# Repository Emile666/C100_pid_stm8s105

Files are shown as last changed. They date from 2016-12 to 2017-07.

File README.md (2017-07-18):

# C100_PID_Upgrade
------------------

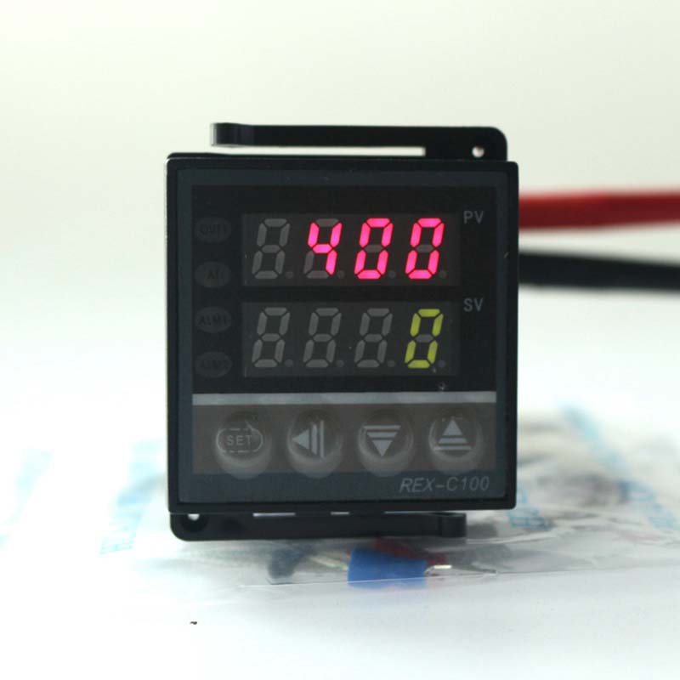
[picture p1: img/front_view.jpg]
C100_front_view
  
*Picture of the frontpanel of a C100 PID controller*

The C100 PID Controller is very easy to find on ebay. For only $10-$15 you can have a PID controller with SSR output. Most package-deals also include a Solid-State Relay (SSR) and a thermocouple (K-type) temperature sensor. Not a bad deal, but if you open the device and look at it from an electrical engineering perspective, things are starting to look a bit different. The main purpose of the upgrade given here is to change the default functionality into that found in the [STC1000p firmware](https://github.com/Emile666/stc1000_stm8/), with the 6 temperature profiles and up-to 9 temperature-time pairs per profile.

The main disadvantages of this controller are:
- K-type thermocouples are not really accurate (±2 °C is quite common)
- The thermocouple interface does not add much to this accuracy. Basically it is a opamp with a gain of 200. Very cheap indeed, no cold-junction compensation and not very accurate.
- Although the PCB has the option of interfacing with a RTD (PT100) sensor, it is not populated. A PT100 would be better suited for a -50 ... + 100 °C range that homebrewers typically use.
- No selectable temperature profiles like the STC1000p has.
- No alarm output relay populated
- Only one frontpanel LED mounted

Advantages are:
- Very nice small package
- Nice frontpanel PCB with 2 x 4-digit 7-segment displays
- Four buttons
- 110-240 V AC power-supply

Internal hardware consists of three Printed-Circuit Boards (PCB): the frontpanel PCB, the power-supply PCB and the main-PCB (as we will call them from now on). The power-supply PCB takes care of converting the AC wall-outlet voltage into a fixed 12 V and a 5 V DC voltage. It also contains the SSR output function.

The frontpanel PCB contains the 7-segment display (top and bottom row of 4-digits), four buttons and one output LED. It is connected to the main-PCB via a 14 pin soldered connection.

The main-PCB contains the microcontroller and the temperaturesensor interface electronics. The microcontroller itself is some crappy Chinese 8051 clone without decent manuals.

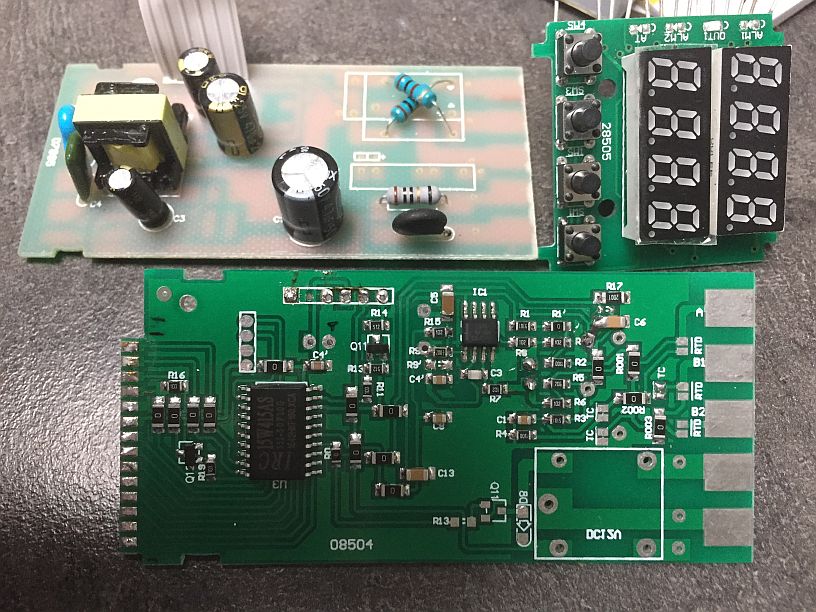
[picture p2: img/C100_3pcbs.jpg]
C100_3_pcbs
  
*Picture of the 3 PCBs taken apart*

# C100 Features after upgrade
---------------------------
- Menu functionality as found in the [STC1000p firmware](https://github.com/Emile666/stc1000_stm8/)
- Alarm relay output added
- Reliable and accurate temperature interface, both for a K-type thermocouple as well as for a PT100 element
- Wireless communication via a **nRF24L01+** device (not implemented yet)
- **I<sup>2</sup>C**-interface available for a DS3231 Real-Time Clock (RTC) interface, so you can have date and time in your C100 (not implemented yet)
- Both a K-type thermocouple and a PT100 are supported. Not at the same time, but if you replace a thermocouple for a PT100 sensor, this will work without further hardware modifications. Which sensor is connected, is detected automatically by the firmware.

Hardware Upgrade
------------------
The power-supply PCB and the frontpanel PCB are kept as they are. Only addition made to the frontpanel PCB is to add 3 more LEDs (ALM1, ALM2 and AT). These are 0805 SMD type LEDs: ALM1 and ALM2 LEDs are red, the AT LED is green.

The main-PCB is desoldered from the frontpanel PCB and thrown away. The interface electronics is horrible and the cheap Chinese microcontroller is of not much use: I don't know how to program it and there's no information how to do this. Instead, a new main-PCB with a decent microcontroller (**STM8S105C6T6**) is made. Schematics and PCB-layout of this new main-PCB is given below.

Software upgrade
-----------------
A port of the STC1000p firmware is made and made available in the src subdirectory (this is work-in-progress)

Schematics and PCB design
-------------------------

The frontpanel PCB is reverse-engineered and schematics are made. This is needed to understand how the frontpanel PCB operates.

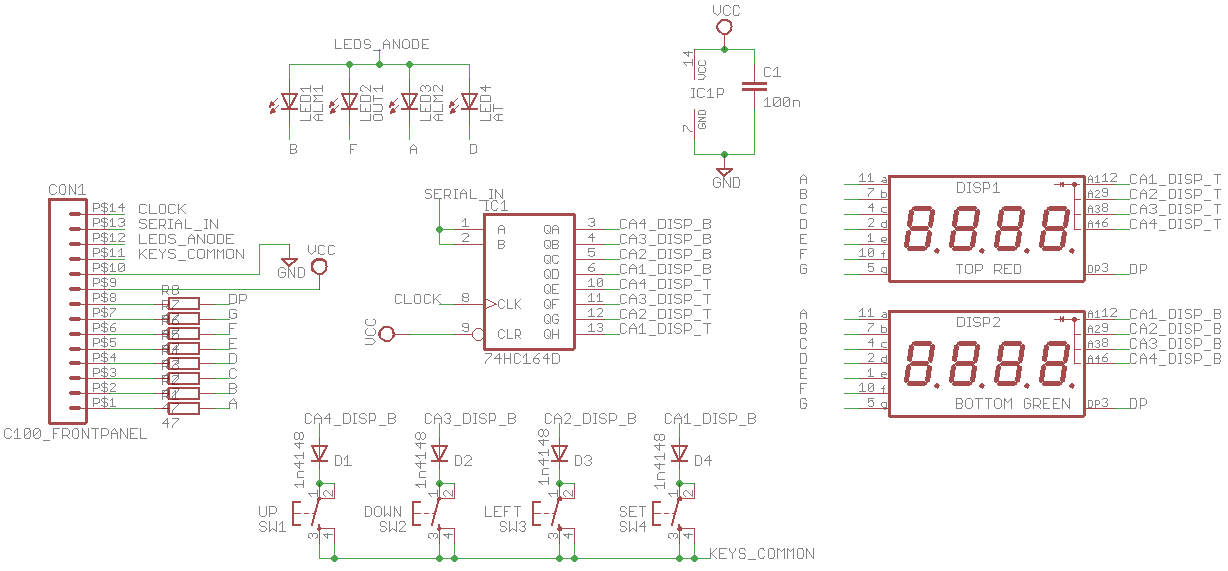
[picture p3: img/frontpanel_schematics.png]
C100 frontpanel
  
*Schematics of the frontpanel of the C100 PID controller*

Some interesting things can be seen from this:
- The Common-Anode lines (8 in total, one for every 7-segment display) are the outputs of a 74HC164 shift-register. The microcontroller controls this with the clock and serial_in lines.
- The keys are multiplexed with the Common-Anode lines from the 7-segment displays. When the displays are addressed, this line needs to be high. Reading the keys is done by enabling the CA lines one by one while checking if KEYS_COMMON line is high (key pressed) or low (not pressed). Furthermore, there's a pull-down resistor on these lines on the main-PCB.
- There's a separate LEDS_ANODE line for the four LEDs (of which only the OUT1 LED is populated). Set this low to disable the LEDs, high with the proper (B, F, A or D) line low enables the LED. A separate PNP transistor to drive this line is populated at the main-PCB.
- The 14 pin connector to the main-PCB is a soldered connection. Place the two PCBs against each other and solder every individual pin.
- The individual segments (a, b, c, d, e, f, g and dp) are connected via a 47R resistor directly to the main-PCB.

The main-PCB is created completely new:

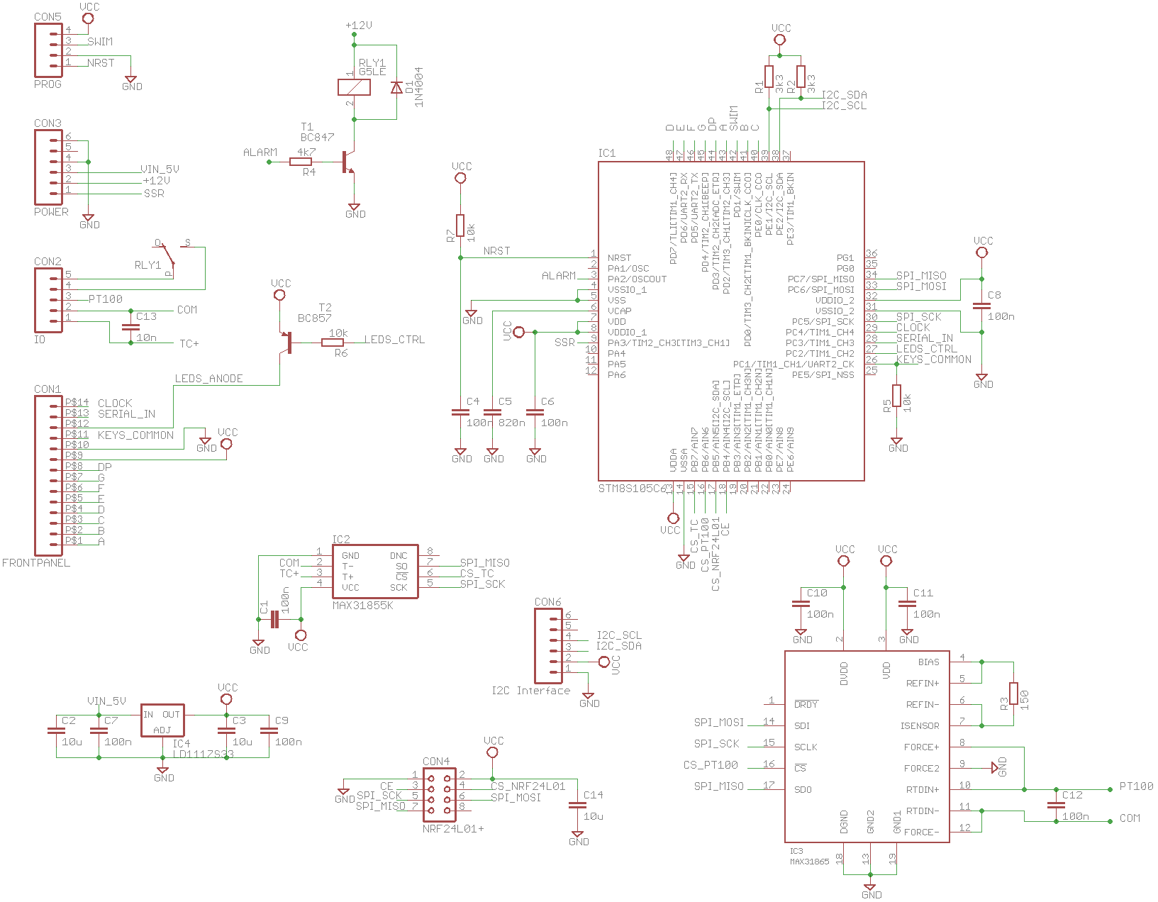
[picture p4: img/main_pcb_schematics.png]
  
*Schematics (new) of the main-PCB of the C100 PID controller*

- The new microcontroller is an **STM8S105C6T6** 48-pin LQFP device. More than capable of running everything. To program this device, the STVD (ST Visual Development) tool is used in combination with the Cosmic C compiler. This will give you 32 Kbyte code-size (and it is free of charge). See the [STC1000p_steroids](https://github.com/Emile666/stc1000p_steroids/) project for details.
- The new PCB has the exact same form-factor as the current PCB. It should therefore be easy to replace it and fit in the current housing
- CON1: the 14 pin soldered connection to the frontpanel
- CON2: this forms the connection with the outside world. The pads are the exact same size as in the original.
- CON3: there's a 6 wire flat-cable coming from the power-supply PCB. Resolder it in the same way as in the original. The flat-cable also contains the SSR-output connection (this function is present at the power-supply PCB).
- CON4: this connector is new and connects to a **nRF24L01+** device for wireless connection to a PC.
- CON5: this one is also new. It is a dedicated connector for programming and debugging. Connect it to the ST-Link V2 USB device (see also the [STC1000p project](https://github.com/Emile666/stc1000_stm8/)).
- CON6: this one is also new and forms an **I<sup>2</sup>C**-interface. Although optional, you could connect a DS3231 Real-Time Clock (RTC) to this. Or something else...
- The entire PCB runs at 3.3 V and has a dedicated voltage regulator (IC4) for it.
- The thermocouple interface is controlled by IC2, a **MAX31855K**, and will give you much more reliable readings than with the stock opamp amplifier. It uses the SPI bus to communicate with the µC.
- There's now also a PT100 interface, controlled by IC3, a **MAX31865**. You can connect either a PT100 sensor or a thermocouple sensor to the device (bot not both at the same time). The PT100 sensor is read first by the firmware. If it detects that it is NOT present, the thermocouple sensor is read.
- An alarm relay is added. It is able to switch 16 A at 230V. During normal operation, it is open and closed when an alarm is present.

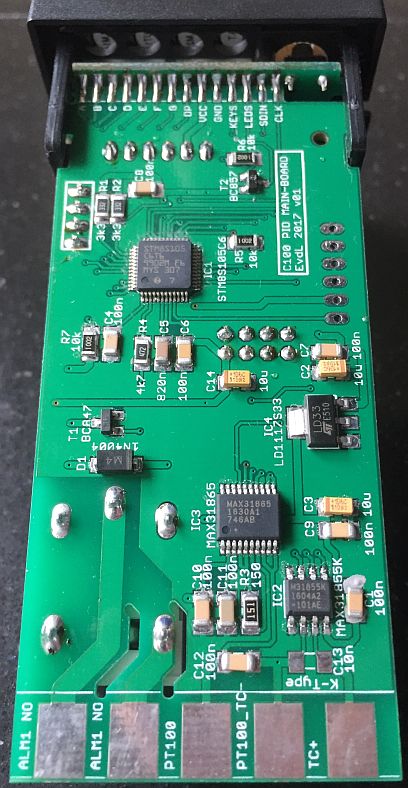
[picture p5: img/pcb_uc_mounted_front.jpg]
C100 main PCB built 1
  
*Picture of the new Main-PCB soldered to the existing frontpanel*

This picture shows how the components were soldered and how the connection to the existing frontpanel is made. The entire PCB fits nicely in the existing housing.

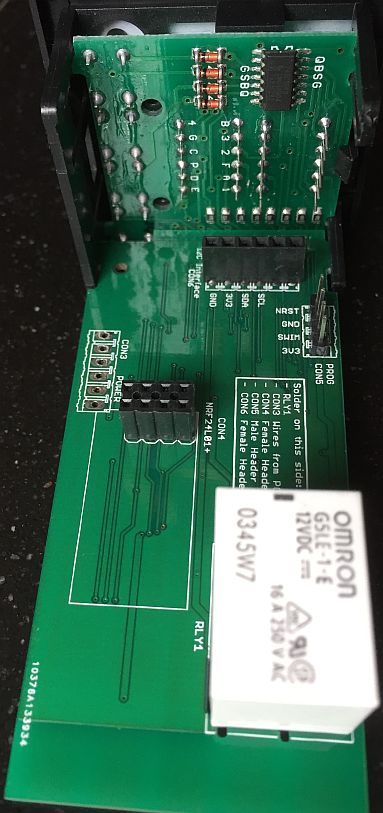
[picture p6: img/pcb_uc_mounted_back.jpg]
C100 main PCB built 2
  
*Solder-side of the new Main-PCB board*

The solder-side contains the alarm relay and also the interfaces for the wireless interface and the Real-Time-Clock (RTC).

I have a limited number of PCBs available. Send me a PM if you would like to have one. But you can also create one yourself with the Eagle .sch and .brd files given here.

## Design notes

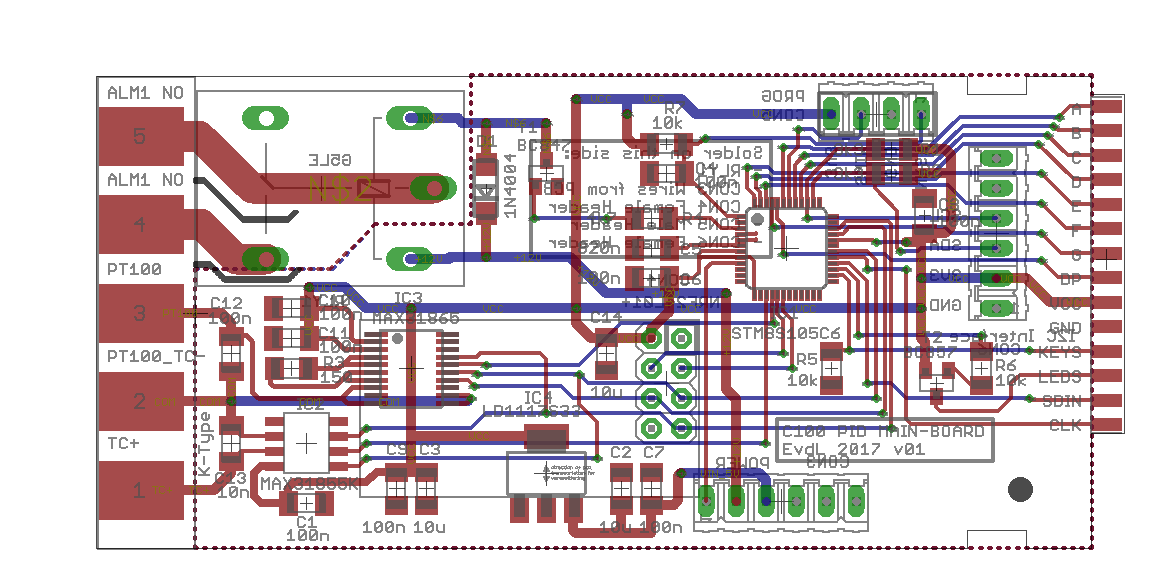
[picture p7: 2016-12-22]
img/main_pcb_new.png

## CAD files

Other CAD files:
c100_pid_stm8s105.stp

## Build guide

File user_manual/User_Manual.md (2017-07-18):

C100-PID STM8 USER MANUAL<br>
=====================

Emile

© 2017

# Changelog

2017:	First version of C100 PID with ported firmware from STC1000p<br>

# Features

* Fahrenheit or Celsius display selectable with **CF** parameter
* Minutes or hours time-base selectable with **Hrs** parameter
* PID-controller selectable with adjustable **Kc**, **Ti**, **Td** and **Ts** parameters
* PID-output polarity selectable with **Kc** parameter. Forward-acting (heating-loop) or reverse-acting (cooling-loop)
* PID-output signal (slow PWM, T=12.5 sec) present at **SSR output** for connection to a Solid-State Relay (SSR)
* K-type thermocouple and PT100 sensor are supported
* Up to 6 profiles with up to 10 setpoints
* Each setpoint can be held for 1-999 hours (i.e. up to ~41 days) or 1-999 minutes (i.e. up to ~16 hours).
* Approximative ramping
* Intuitive menus for configuring
* User definable alarm relay when temperature is out of or within range
* Easy displaying of setpoint, actual temperature and PID-output (%)

# Using the C100 PID firmware

## Navigation and menus

By default the current temperature is displayed in °C or °F on the top row of the display, depending on the **CF** parameter. Pressing the 'Set' button enters the menu. Pressing button 'Up' and 'Down' scrolls through the menu items. 
Button 'Set' selects and 'Left' button steps back or cancels current selection.

The menu is divided in two steps. When first pressing 'Set', the following choices are presented:

|Menu item|Description|
|---|---|
|Pr0|Set parameters for profile 0|
|Pr1|Set parameters for profile 1|
|Pr2|Set parameters for profile 2|
|Pr3|Set parameters for profile 3|
|Pr4|Set parameters for profile 4|
|Pr5|Set parameters for profile 5|
|Par|Parameter settings menu|
*Table 2: Menu items*

Selecting one of the profiles enters the submenu for that profile.

Pr0-5 submenus have the following items (x is the number of the profile itself):

|Sub menu item|Description|Values|
|---|---|---|
|SPx0|Set setpoint 0|-40.0 to 140͒°C or -40.0 to 250°F|
|dhx0|Set duration 0|0 to 999 hours|
|...|Set setpoint/duration x|...|
|dhx8|Set duration 8|0 to 999 hours|
|SPx9|Set setpoint 9|-40.0 to 140°C or -40.0 to 250°F|
*Table 3: Profile sub-menu items*

You can change all the setpoints and durations associated with that profile from here. When running the programmed profile, *SPx0* will be the initial setpoint, it will be held for *dhx0* hours (unless ramping is used). 
After that *SPx1* will be used as setpoint for dhx1 hours. The profile will stop running when a duration (*dh*) of 0 hours OR last step is reached (consider *dh8* implicitly 0). When the profile has ended, C10-PID will automatically continu using the last reached setpoint. (So I guess you could also consider a *dh* value of 0 as infinite hours).

The settings menu has the following items:

|Sub menu item|Description|Values|
|---|---|---|
|SP|Set setpoint|-40 to 140°C or -40 to 250°F|
|hy|Set hysteresis|0.0 to 5.0°C or 0.0 to 10.0°F|
|tc|Set temperature correction for thermocouple sensor|-5.0 to 5.0°C or -10.0 to 10.0°F|
|tc2|Set temperature correction for PT100 sensor|-5.0 to 5.0°C or -10.0 to 10.0°F|
|SA|Setpoint alarm|0 = off, -40 to 40°C or -80 to 80°F|
|St|Set current profile step|0 to 4 (8)|
|dh|Set current profile duration|0 to 999 hours|
|rP|Ramping|0 = off, 1 = on|
|cF|Celsius or Fahrenheit display|0 = Celsius, 1 = Fahrenheit|
|At|Enable auto-tuning for PID-controller|0 = off, 1 = on|
|HrS|Select Hours or Minutes time-base|0 = minutes, 1 = hours|
|Hc|Kc parameter for PID-controller in %/°C|-9999 to 9999|
|Ti|Ti parameter for PID-controller in seconds|0 to 9999|
|Td|Td parameter for PID-controller in seconds|0 to 9999|
|Ts|Ts parameter for PID-controller in seconds|0 to 9999|
|rn|Set run mode|Pr0 to Pr5 and th|
*Table 4: Settings sub-menu items*

**Setpoint**, well... The desired temperature to keep. The way C100-PID firmware works, setpoint is *always* the value the PID-controller strives towards, even when running a profile. What the profile does is simply setting the setpoint at given times.

**Hysteresis**: This parameter is used when the thermostat controls the temperature (**Ts** is set to 0). This parameter then controls the allowable temperature range around the setpoint where the thermostat will not change state. For example: in a cooling-loop (**Hc** < 0) and the temperature is greater than setpoint + hysteresis, then the SSR-output will be engaged. Once the temperature reaches setpoint again, the SSR-output will be disengaged.
Similarly: in a heating-loop (**Hc** > 0) and the temperature is smaller than setpoint - hysteresis, then the SSR-output will be engaged. Once the temperature reaches setpoint again, the SSR-output will be disengaged.

**Temperature correction**, will be added to the thermocouple temperature sensor, this allows the user to calibrate the temperature reading. A K-type thermocouple sensor is the default sensor to use for the C100-PID. 

**Temperature correction 2**, same as *temperature correction*, but for the PT100 temperature sensor. A PT100 temperature sensor is more precise than a thermocouple, so if you want accurate temperature readings, it is better to buy a PT100 sensor and connect this to the C100-PID.

**Setpoint alarm**, if setpoint alarm is greater than 0.0, then the alarm will sound once temperature differs from *SP* by more than *SA* degrees (this can be useful to warn against malfunctions, such as fridge door not closed or probe not attached to carboy). If *SA* is less than 0.0, then the alarm will sound if the temperature does **NOT** differ by more than (-) *SA* degrees (this could be used as an indication that wort has finally reached pitching temp). If *SA* is set to 0.0, the alarm will be disabled. If the alarm is tripped, then the buzzer will sound and the display will flash between temperature display and showing "SA", it will not however disengage the outputs and the unit will continue to work as normal. Please note, that care needs to be taken when running a profile (especially when not using ramping or with steep ramps) to allow for a sufficiently large margin, or the alarm could be tripped when setpoint changes.

**Current profile step** and **current profile duration**, allows 'jumping' in the profile. Step and duration are updated automatically when running the profile, but can also be set manually at any time. Note that profile step and profile duration are the variables directly used to keep track of progress in a profile. Little or no validation is made of what values are entered. It is up to the user to know what he/she is doing by changing these values. Changing these values will not take effect until next point in profile is calculated, which could be as much as one hour. Every hour, current duration, *dh* (and if next step is reached, also current step, *St*) is updated with new value(s). That means in case of a power outage, STC-1000p-STM8 will pick up (to within the hour) from where it left off. Current profile step and current profile duration are only available in the menu when a profile is currently running.

**Ramping** can be used to gradually increase the setpoint when going from one setpoint to another. See below for a more detailed explanation.

**Celsius or Fahrenheit** can be used to set display mode for temperatures to Celsius or Fahrenheit. Note that the values stored in EEPROM are not directly changed with it, so if you change this, you need to make sure that the stored parameters are updated!

**Auto Tuning** modus is a separate process where the C100-PID tries to find optimum settings for **Hc**, **Ti** and **Td**. Note that the **Ts** needs to be set to a non-zero value first. The auto-tuning algorithm forces the pid-output to certain values and observes the temperature. From this, optimum settings are calculated for the PID parameter. This does not work for every plant, so use this with care! This is a future option and not implemented yet in this firmware.

**Hours or Minutes** can be used to select between a time-mode in hours or minutes. Typically the minutes time-mode is selected when you want to control a brewing-session. When controlling a fermentation in a climate controlled chamber, you typically select hours.

**Hc**, this is the proportional gain for the PID controller. It also selects the PID-mode: **forward-acting** (**Hc** > 0) or **reverse-acting** (**Hc** < 0). See below for a more detailed explanation.

**Ti**, this is the integral time-constant in seconds for the PID controller. See below for a more detailed explanation.

**Td**, this is the differential time-constant in seconds for the PID controller. See below for a more detailed explanation.

**Ts**, this is the sample-time in seconds for the PID controller. The PID-controller runs every **Ts** seconds. When set to 0, the PID-controller is disabled and normal thermostat (on-off) control is enabled. If you set this time too small, the pid-controller becomes too sensitive for changes in temperature. A decent value for temperature control is around 20-30 seconds (yes, that slow! It's temperature remember, doesn't change that quick). See below for a more detailed explanation.

**Run mode**, selecting *Pr0* to *Pr5* will start the corresponding profile running from step 0, duration 0. Selecting *th* (when **Ts** = 0) or *PId* (when **Ts** > 0) will switch to thermostat/PID mode, the last setpoint from the previously running profile will be retained as the current setpoint when switching from a profile to thermostat/PID mode.

## Thermostat mode (**Ts** = 0)

When mode is set to thermostat (the **Ts** parameter needs to be set to 0), setpoint, *SP*, will not change and the controller will aim to keep the temperature to within the range of *SP* ± *hy*. Much like how the normal STC-1000 firmware works. The thermostat control runs once every second. The PID-controller output with the **SSR output** is set to 100 % (fully-on) and 0 % (fully-off).

## PID-Control mode (**Ts** > 0)

When the **Ts** parameter is set to a value > 0, the PID-controller is enabled and thermostat-control is disabled. The PID-controller uses a sophisticated algorithm (a Takahashi Type C velocity algorithm) where the new output value is based upon the previous output value. The derivation of the algorithm for this controller is given in the .pdf document [PID Controller Calculus](./PID_Controller_Calculus.pdf).
The PID-controller is controlled with the *proportional gain*, *integral time-constant*, *differential time-constant* and the *Sample-Time*. They all work closely together. For more information on how to select optimum settings for a PID-controller, please refer to http://www.vandelogt.nl/uk_regelen_pid.php

The pid-output is a percentage between 0.0 and +100.0 %. It is in E-1 %, so a value of 123 actually means 12.3 %. This value can be seen by pressing the LEFT button. This is where the polarity of the **Hc** parameter comes into play. Set **Hc** to a positive value for a so-called **direct-acting** process loop. This means that when the PID-output increases, the temperature (which is the process variable, or PV) also eventually increases. Of course, a true process is usually a complex transfer function that includes time delays. Here, we are only interested in the direction of change of the process variable in response to a PID-output change. Most process loops will be **direct-acting**, such as a temperature loop. An increase in the heat applied increases the temperature. Accordingly, direct-acting loops are sometimes called heating loops.

Direct-Acting<br>
*A Direct-Acting process control loop*

If the **Hc** parameter is set to a negative value, a so-called **reverse-acting** process loop is selected. A **reverse-acting** loop is one in which the process has a negative gain, as shown below. An increase in the control output results in a decrease in temperature. This is commonly found in refrigeration controls, where an increase in the cooling input causes a decrease in the process variable (the temperature). Accordingly, reverse-acting loops are sometimes called cooling loops.

Reverse-Acting<br>
*A Reverse-Acting process control loop*

**Source:** the above text and both images are copied from (and slightly adapted) from the DL05 Micro PLC User Manual, which has an excellent chapter (chapter 8) on PID-control.

The pid-output percentage is available at the **SSR output** as a slow PWM signal (period-time is 12.5 seconds), with the duty-cycle corresponding with the PID-output percentage.
For example: if the pid-output is equal to 200 (20.0 %), the **SSR output** is low (0 V) for 2.5 seconds and high (+5 V) for 10 seconds. This repeats continuously until another pid-output percentage is calculated. The Heating LED (when **Hc** is > 0) or the Cooling LED (when **Hc** is < 0) blinks at the same rate, so you can always see if the SSR is switched on.

## Running profiles

By entering the 'rn' submenu under settings and selecting a profile, the current duration, *dh*, and current step, *St*, is reset to zero and the initial setpoint for that profile, *SP0*, is loaded into *SP*. Even when running a profile, *SP* will always be the value the controller aims to keep. The profile simple updates *SP* during its course. When a profile is running the 'Set' LED on the display will be lit as an indication.

From the instant the profile is started a timer will be running, and every time that timer indicates that one hour has passed, current duration, *dh*, will be incremented. If and only if, it has reached the current step duration, *dhx*, current duration will be reset to zero and the current step, *St*, will be incremented and the next setpoint in the profile will be loaded into *SP*.  Note that all this only happens on one hour marks after the profile is started.

So, what will happen if the profile data is updated while the profile is running? Well, if that point has not been reached the data will be used. For example profile is running step 3 (with the first step being step 0). Then *SP3* has already been loaded into *SP*, so changing *SP0* - *SP3* will not have any effect on the current run. However, the duration *dh3* is still being evaluated every hour against the current duration, so changing it will have effect. 

Changing the current duration, *dh*, and current step, *St*, will also have effect, but the change will not be immediate, only on the next one hour mark will these new values be used in the calculation. You will need to know what you are doing when changing these values manually, but correctly used, it could come in handy.

Changing the setpoint, *SP*, when running a profile, will have immediate effect (as it is used by thermostat control), but it will be overwritten by profile when it reaches a new step.

Once the profile reaches the final setpoint, *SP5*, or a duration of zero hours, it will switch over to thermostat mode and maintain the last known setpoint indefinitely.

Finally, to stop a running profile, simply switch to thermostat mode.

## Ramping

The essence of ramping is to interpolate between the setpoints in a profile. This allows temperature changes to occur gradually instead of in steps.

Unfortunately, due to hardware limitations, true ramping (or true interpolation), is not feasible. So instead, an approximative approach is used.

Each step is divided into (at most) 64 substeps and on each substep, setpoint is updated by linear interpolation. The substeps only occur on one hour marks, so if the duration of the step is less than 64 hours, not all substeps will be used, if the duration is greater than 64 hours, setpoint will not be updated on every one hour mark, for example if duration is 192 hours (that is 8 days), setpoint will be updated every third hour).

Note, that in order to keep a constant temperature with ramping enabled, an extra setpoint with the same value will be needed (C100-PID will attempt to ramp between all setpoints, but if the setpoints are the same, then the setpoint will remain constant during the step).

You can think of the ramping as being true, even if this approximation is being used, the only caveat is, if you need a long ramp (over several days or weeks) and require it to be smoother. Then you may need to split it over several steps.

Another tip would be to try to design your profiles with ramping in mind, if possible (that is include the extra setpoints when keeping constant temperature is desired), even if you will not use ramping. That way, the profiles will work as expected even if ramping is enabled.

## Additional features

**Sensor alarm**, if the measured temperature is out of range (indicating the sensor is not connected properly or broken), the alarm-relay is enabled and display will show 'AL01'.

**Power off**, pressing and holding LEFT button for a few seconds when the controller is not in menu (showing current temperature), will disable everything and show 'OFF' on the display. To really power off, you need to cut mains power to the device. The soft power off state will remain after a power cycle. Long pressing the power off button again will bring it out of soft power off mode.

By pressing and holding 'up' button when temperature is showing, the firmware version number will be displayed.

By pressing and holding 'down' button when temperature is showing, *th* will be displayed if the controller is in thermostat mode or *PId* when in PID-mode. If a profile is running, it will cycle through *Prx* (where *x* is the profile number), current profile step and current profile duration, to indicate which profile is running and the progress made.

# Frontpanel LEDs
The C100-PID has four frontpanel LEDs and have the following meaning:
- ALM1: this LED corresponds to the alarm relay and lights when no temperaturesensor is connected. It also lights when the **SA** parameter is set and the temperature is out of range.
- OUT1: this corresponds to the SSR output. If the PID-output is 10 %, this LED is on for 1.25 seconds and off for 11.25 seconds
- ALM2: this LED is set upon entering a parameter change menu. It starts to blink when you are about to save a new value for a parameter
- AT: this LED blinks when a temperature profile is active

# Development

C100-PID is written in C and compiled using STVD with the Cosmic SMT8 C compiler. Best thing to do is to ask for a free license (www.cosmic-software.com), install the toolset and then install the STVD IDE. In this way, STVD integrates the Cosmic toolchain in its IDE.

## Useful tips for development

* You will need the STM8 reference-manual (the datasheet merely lists the hardware related issues).

* The Cosmic STM8 compiler has a code-size limit of 32 Kbytes, which is sufficient for our STM8 µC.

* The STVD IDE organises the source-files in projects (.stp) and workspaces (.stw). Use only 1 project per workspace. The default workspace file for C100-PID is C100_pid_stm8s105.stw.

* A separate scheduler (non pre-emptive) has been added to address all timing issues. See the source files scheduler.c and scheduler.h

* Hardware routines (interrupts, ADC, eeprom) have been copied from the STC1000p project.

# Other resources

Project home at [Github](https://github.com/Emile666/stc1000_stm8/)

# Acknowledgements

Many thanks to Mats Staffansson (https://github.com/matsstaff/stc1000p) for initial development of a STC1000p on the A400_P hardware (containing a **PIC16F1828** microcontroller). The **STM8S003F3** device is a bit more advanced and I was intrigued by the idea of doing the same as Mats has done. In the end I ended with a few more features than he had (and also fewer, since he had more different firmwares).

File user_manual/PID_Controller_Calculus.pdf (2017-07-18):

PID Controller Calculus for STC1000p-STM8

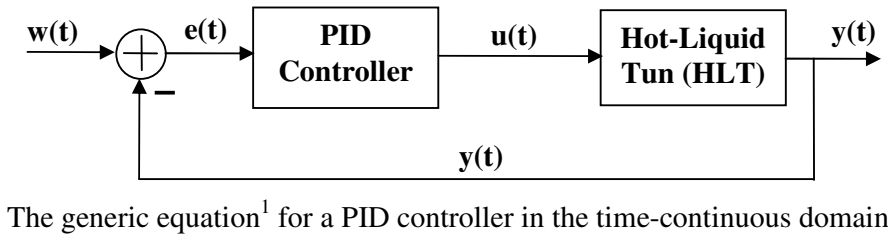
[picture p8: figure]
The generic equation¹; PID Controller; Hot-Liquid Tun (HLT)

Author: Emile van de Logt | Page 1/7

### 1. Introduction

This document describes the derivation of a PID controller that can be implemented in the STC1000p. The PID controller should be capable of controlling the temperature to within 0.1 °C.

This document contains the following information
- Chapter 2: the time-continuous representation for a PID controller
- Chapter 3: Derivation of an improved algorithm (a so-called ‘type C’ PID controller)
- Chapter 4: Description of algorithms for finding the optimum set of Kc, Ti

, Td and Ts
values for the PID controller

### 2. time-continuous representation of a PID controller

for a PID controller in the time-continuous domain is:

= | + | + ∫
dt

de t
dtte | T
T
tu | K | te | d

i

c

)(
)( | .

1
)( | )(. | (eq. 01)
With: Kc = Kp | Proportional Gain (for our temperature controller, unity is [% / °C])
Ti
= Kc / Ki | Time-constant Integral gain [sec.]
Td = Kd / Kc | Time-constant Derivative gain [sec.]
Ts | Sample period (default value is 20 seconds)
w(t) | Setpoint (SP) value for temperature
e(t) | error signal = setpoint w(t) – process variable y(t)
u(t) | PID output signal, also called Gamma, ranges from [0..100 %]
y(t) | process variable PV = measured temperature

### 3. Derivation of a Type C PID controller

There are three types of PID equations (see http://bestune.50megs.com/typeabc.htm) , with type C being the preferred one. Equation eq. 01 are type A equations, since the P- and the D-term both contain the setpoint. Any changes in the set-point may cause an unwanted change in the PID output u(t).
Removing the set-point from the D-term results in a type B controller. The type C controller has also removed the set-point from the P-term, resulting in an even better PID controller implementation.

Start with the generic equation for a PID controller again:

= | + | + ∫
dt

de t
dtte | T
T
tu | K | te | d

i

c

)(
)( | .

1
)( | )(. | (eq. 01)

1
This is the ideal, textbook version of a continuous-time PID controller. See “Digital Self-Tuning Controllers”, ISBN 1-85233-980-2, Bobál et.al., page 54.

Author: Emile van de Logt | Page 2/7

Now differentiate both sides:

= | + | + | 2

2
)(
)( | )(

)(
dt

d te
T
T

te
dt

de t
K
dt

du t

d
i

c

(eq. 02)

Now transform equation eq. 02 to the time-discrete domain, using backwards differentiation:

( | )
+ | + | − | +

−
+=

−

− | −
− | −
2 | 1 | 2

1 1
k

.2 k k

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
k | k
e | e | e
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
(eq. 03)

Equation eq.03 can now also be written as:
( | ) | ( | )
= | −1 + | − −1 + | + | −1 − | − | −2

.2.

k | k | k
s

d

i

ks
k | k | c | k | k
y | y | y
T

T
T

T e
u | u | K | e | e | (eq. 04)

Equation 04 is a type B equation, because the differential term no longer depends upon wk (remember that ek = wk – yk).

We will now transform equation eq.04 into a type C equation (eq. 05), by also removing the setpoint wk from the proportional part (again: ek = wk – yk):

( | )
= | −1 + | −1 − | + | + | −1 − | − | −2
. | . | .2.
k | k | k
s

d
k
i

s
k | k | c | k | k
y | y | y
T

T
e
T

T
u | u | K y | y | (eq. 05)

Here, yk is the process variable, which is the actual temperature of the HLT. This is the well-known relation given by Takahashi²
, also known as the Takahashi PID controller.

Equation 05 is used directly in pid_ctrl().

2
Y. Takahashi, C. Chan and D. Auslander, “Parametereinstellung bei linearen DDC-algorithmen”, Regelunstechnik und Prozessdatenverarbeitung, vol. 19, pp. 237-284, 1971

Author: Emile van de Logt | Page 3/7

### 4. Finding the optimum set of PID parameters

Finding the optimum parameters for a PID controller can be difficult. Optimum means that the set-point temperature is reached as quickly as possible with overshoot minimised.

Three well-known algorithms for determining the PID parameters are described here:
- Ziegler-Nichols open-loop: set PID controller to a certain output and determine slope and dead-time of HLT system
- Ziegler-Nichols closed-loop: measure step-response
- Cohen-Coon: also a closed-loop method. Measure step-response
- Integral of the time weighted absolute error (ITAE): results in the best performance. The error signal is minimised (over time).

Some terms are frequently used in this document:
- Dead-time θ: this is the time-delay between the initial step and a 10% increase in the process variable (the HLT temperature in our case).
- Khlt: the gain of the HLT-system. The HLT-system receives the Gamma value (PID output) as input and has the HLT temperature as output. Unity of Khlt is [°C / %].
- τhlt: the time-constant of the HLT-system. The HLT-system can be described with a first-order process model with time-delay (FOPTD). The transfer function for this model is:

. 1

)(

+

=

−

s

K e
HLT s

hlt

s
hlt
τ

θ

- a*: the normalised slope of the step response. Equal to ∆T / (∆t. ∆p) with:
- ∆T: change in temperature [°C]
- ∆t : change in time [seconds]
- ∆p: change in PID controller output [%]

With these three parameters, the optimum PID parameters are determined using table 1 on the next page (values are given both for PID operation and for PI-only operation):

Author: Emile van de Logt | Page 4/7
Method: / Parameter: | Kc [% / °C] | Ti [seconds] | Td [seconds]
Ziegler-Nichols Open-loop | 2,1 Kc = θ . * a | Ti = .0,2 θ | Td = .5,0 θ
Ziegler-Nichols Open-loop | 9,0 Kc = θ . * a | Ti = .33,3 θ | - -
Ziegler-Nichols Closed-loop | .2,1 τ hlt K = c θ K . hlt | Ti = .0,2 θ | Td = .5,0 θ
Ziegler-Nichols Closed-loop | .9,0 τ K = hlt c θ K . hlt | Ti = .33,3 θ | - -
Cohen-Coon | τ θ 4 hlt K = . + c K . θ .4 τ 3 hlt hlt | .32 τ + .6 θ hlt Ti = θ . .13 τ + .8 θ hlt | .4 τ hlt Td = θ . .2 θ + .11 τ hlt
Cohen-Coon | τ θ 9 hlt K = . + c K . θ .12 τ 10 hlt hlt | .30 τ + .3 θ hlt Ti = θ . .9 τ + .20 θ hlt | - -
ITAE-Load | − 947,0 357,1 θ K = . c K τ hlt hlt | 738,0 τ θ = hlt Ti . 842,0 τ hlt | 995,0 θ Td = 381,0 . τ hlt . τ hlt
ITAE-Load | − 977,0 859,0 θ K = . c K τ hlt hlt | 680,0 τ θ = hlt Ti . 674,0 τ hlt | - -

Table 1: optimum PID parameters for the various methods

To be able to find these three parameters accurately, two experiments need to be conducted. These two experiments are described in the next two paragraphs.
The last paragraph (§ 4.3) shows the calculated PID parameters for all these methods.

PID Controller Calculus for

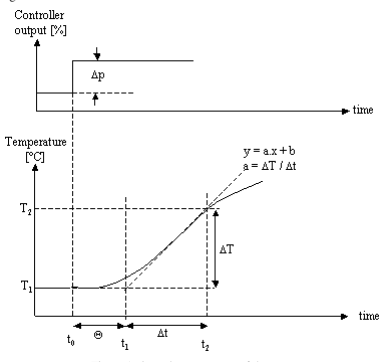
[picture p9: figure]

Author: Emile van de Logt

### 4.1 Experiment 1: Determine dead

Manually set the PID-controller output (“gamma”) to a certain value (e.g heavy load, 100 % is recommended (more acc
the system, a lower value to start with is better.
curve in figure 1.

Figure 1: Open

Calculate the average slope of the rise
Calculate the normalised slope a*, which is defined The dead-time θ is defined as the time between t done quite accurately).

Experimental data: HLT filled with 85 L water
19:08:20 | t0, the PID controller output gamma was set to 100 %,
| Step-response up to 55.00
19:12:25 | Thlt = 48,18 °C (≥ T
19:27:21 | Thlt = 54,25 °C (≥ T

Regression analysis of the data between 19
| y = a.x + b = 0,0334x + 48,278
Here, every data-point for x represents 5 seconds. Therefore, the av
| a = 0,0334 °C / 5 sec. = 6,68E
Now solve where this curve hits the Tenv line:
| x = (47.41 – 48.278) / 6.68E The dead-time moment is then 19:12:25
| Therefore, the dead

-time Θ of HLT
controller output (“gamma”) to a certain value (e.g. 20 %). In case of a urate), but if you don’t know the performance of The temperature starts to increase and follows the

Figure 1: Open-loop response of the system

(a = ∆T / ∆t) by using regression analysis if possible. as: a* = a / ∆p.

### 0 and t1 (by using regression analysis, this can be

, the PID controller output gamma was set to 100 %, T1 = 47,41 °C °C, ∆T = 7,59 °C
T1 + 10%.∆T = 48,17 °C)
T1 + 90%.∆T = 54,24 °C)

:12 :25 and 19:27 :21 resulted in the following: R²
= 0,9995
point for x represents 5 seconds. Therefore, the average slope a is equal to: C / 5 sec. = 6,68E-03 °C/second (which is 0,4 °C/minute)

-03 = -130 seconds (or 2 minutes and 10 seconds) time moment is then 19:12:25 – 2:10 = 19:10:15
-time θ = 19:10:15 – 19:08:20 = 1:55 = 115 seconds

Page 5/7

-system
. 20 %). In case of a

PID Controller Calculus for

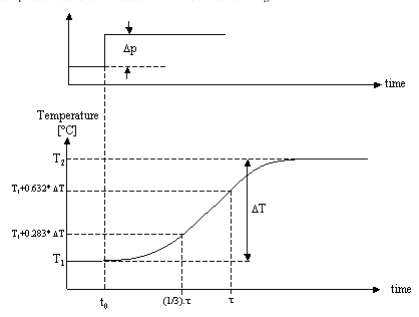
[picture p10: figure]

Author: Emile van de Logt

The normalised slope a* is equal to :
a* = a / ∆p = 6,68E

### 4.2 Experiment 2: Determine gain K

Manually set the PID-controller output temperature starts to increase and follows the curv

Because of the large time-constant presumably present in the HLT system, the not very accurate in determining the dead
experiments (theoretically, the step
determine the three parameters).

Experimental data: HLT filled with 85 L
09:49:04 | t0, the PID controller output gamma was set to 20 %,
20:24:03 | Experiment stopped, T = 52,98
Regression analysis (2
Maximum found at 21:20:44 (8300 ticks of 5 seconds) ∆T = 52,989 – 19,20 = 33,789
T(t = 1/3.τhlt) = T1
T(t = τhlt) = T1 + 0,632 *
Solve for τhlt:
Solve for Gain Khlt: | Khlt = ∆T /

:
-05 °C/(%.second)

hlt and time-constant τhlt (“gamma”) to a certain value (e.g. 20 %). The e in figure 2.

Figure 2: Step response of the system

constant presumably present in the HLT system, the -time θ. This is the mean reason to conduct two -response would give you all the required informatio

water
, the PID controller output gamma was set to 20 %, T1 = 19,20 °C °C.
nd order polynomial) used to find maximum. Maximum found at 21:20:44 (8300 ticks of 5 seconds). T2 = 52,989 °C 19,20 = 33,789 °C
+ 0,283 * ∆T = 28,762 °C => 1/3.τhlt = 6599 seconds
+ 0,632 * ∆T = 40,555 °C => τhlt = 16573 seconds τhlt – 1/3. τhlt = 16573 – 6599 => τhlt = 14961 seconds ∆p = 33,789 °C / 20 % = 1,689 °C / %

Page 6/7

hlt of HLT-system

step response is

n to

Author: Emile van de Logt | Page 7/7

### 4.3 Calculation of PID parameters for the various methods

In the previous paragraphs, the following parameters were found:
- | dead-time θ | = 115 seconds
- | Gain Khlt | = 1,689 °C / %
- | Time-constant τhlt | = 14961 seconds
- | Normalised slope a* | = a / ∆p = 6,68E-05 °C/(%.second)

Kc [%/°C] Ti [sec] Td [sec]
Ziegler-Nichols Open Loop | 156,2 | 230,0 | 57,5 PID
| 117,2 | 383,0 | - - PI
Ziegler-Nichols Closed Loop | 92,4 | 230,0 | 57,5 PID
| 69,3 | 383,0 | - - PI
Cohen-Coon | 102,8 | 282,2 | 41,8 PID
| 69,4 | 377,2 | - - PI
ITAE-Load | 80,8 | 489,0 | 44,9 PID
| 59,2 | 810,2 | - - PI
Table 2: Calculation of parameters for the various methods

Version History
Date | Version | Description
8-11-2016 | V0.1 | First version for Github STC1000p-STM8

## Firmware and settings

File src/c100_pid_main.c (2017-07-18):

/*==================================================================
  File Name    : c100_pid_main.c
  Author       : Emile
  ------------------------------------------------------------------
  Purpose : This is the main-file for the c100_pid project.

  ------------------------------------------------------------------
  C100_PID is free software: you can redistribute it and/or modify
  it under the terms of the GNU General Public License as published by
  the Free Software Foundation, either version 3 of the License, or
  (at your option) any later version.
 
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
  You should have received a copy of the GNU General Public License
  along with C100_PID.  If not, see <http://www.gnu.org/licenses/>.
  ------------------------------------------------------------------
  $Log: $
  ==================================================================
*/ 
#include "c100_pid_main.h"
#include "stdint.h"
#include "delay.h"
#include "stc1000p_lib.h"
#include "scheduler.h"
#include "spi.h"

// Global variables
bool      auto_tuning  = false;    // true = PID auto-tuning
bool      relay_alarm1 = false;    // true = sound alarm
uint16_t  leds_out;                // Four LEDs on frontpanel (ALM1, OUT1, ALM2, AT)
int16_t   temp_tc_pt;              // Temperature in E-1 °C from TC or PT100
int32_t   temp_tc_fil = TEMP_ROOM; // Filtered temperature in E-1 °C from TC
int32_t   temp_pt_fil = TEMP_ROOM; // Filtered temperature in E-1 °C from PT100
bool      temp_err = false;        // 1 = no temperature sensor present
uint8_t   mpx_nr = 0;              // Used in multiplexer() function
int16_t   pwr_on_tmr = 1000;       // Needed for 7-segment display test
uint8_t   hc164_val;

uint8_t std[4] = {STD_LED_OFF, STD_LED_OFF, STD_LED_OFF, STD_LED_OFF};
uint8_t blink_tmr[4];

// External variables, defined in other files
extern int16_t  @eeprom eedata[];                // Link to .eeprom section
extern uint8_t  top_100, top_10, top_1, top_01;  // 7-segments top row: 100s, 10s, 1s and 0.1s
extern uint8_t  bot_100, bot_10, bot_1, bot_01;  // 7-segments bottom row: 100s, 10s, 1s and 0.1s
extern bool     pwr_on;                          // True = power ON, False = power OFF
extern uint8_t  sensor2_selected; // DOWN button pressed < 3 sec. shows 2nd temperature / pid_output
extern bool     minutes;          // timing control: false = hours, true = minutes
extern bool     menu_is_idle;     // No menus in STD active
extern bool     fahrenheit;       // false = Celsius, true = Fahrenheit
extern int16_t  setpoint;        // local copy of SP variable
extern int16_t  kc;              // Parameter value for Kc value in %/°C
extern uint8_t  ts;              // Parameter value for sample time [sec.]
extern int16_t  pid_out;         // Output from PID controller in E-1 %
extern uint32_t t2_millis;       // Updated in TMR2 interrupt

/*-----------------------------------------------------------------------------
  Purpose  : This routine sets the HC164 shiftregister to a value x.
  Variables: -
  Returns  : -
  ---------------------------------------------------------------------------*/
void set_hc164(uint8_t x)
{
    uint8_t i, j, p = 0x80;
    
    hc164_val = x; // save value for read_buttons() function
    SET_CLK_0;     // CLK  = 0
    SET_SDIN_0;    // SDIN = 0
    for (i = 0; i < 8; i++)
    {
        if (x & p) SET_SDIN_1;
        else       SET_SDIN_0;
        SET_CLK_1;
        p >>= 1;
        for (j = 0; j < 10; j++); // small delay
        SET_CLK_0;
    } // for i
} // set_hc164()

/*-----------------------------------------------------------------------------
  Purpose  : This routine set one frontpanel LED ON, OFF or Blinking.
             Blinking-rate can be set fast or slow
  Variables: nr: unique number for LED [0..3]
            led: bit-define in leds_out for one of 4 LEDs: 1 = ON, 0 = OFF
      blink_msk: bit-define in leds_out for one of 4 LEDs: 1 = Blinking, 0 = not
 blink_rate_msk: bit-define in leds_out for one of 4 LEDs: 1 = Blink fast, 0 = Blink slow
  Returns  : -
  ---------------------------------------------------------------------------*/
void set_one_led(uint8_t nr, uint16_t led, uint16_t blink_msk, uint16_t blink_rate_msk)
{   
   uint8_t blink_rate;
   
   if (leds_out & blink_rate_msk)
        blink_rate = LED_BLINK_FAST;
   else blink_rate = LED_BLINK_SLOW;
   
   switch (std[nr])
   {
       case STD_LED_OFF:
          PD_ODR |= led; // LED off
          if (leds_out & led)
          {
             if (leds_out & blink_msk)
             {
                  std[nr]       = STD_LED_BLINK1;
                  blink_tmr[nr] = 0;
             }
             else std[nr] = STD_LED_ON;
          } // if
          // else remain in this state
          break;
       case STD_LED_ON:
          PD_ODR &= ~led; // LED on
          if (!(leds_out & led))
             std[nr] = STD_LED_OFF;
          else if (leds_out & blink_msk)
          {
             std[nr]       = STD_LED_BLINK1;
             blink_tmr[nr] = 0;
          } // else if
          break;
       case STD_LED_BLINK1:
          PD_ODR &= ~led; // LED on
          if (!(leds_out & led))
             std[nr] = STD_LED_OFF;
          else if (!(leds_out & blink_msk))
             std[nr] = STD_LED_ON;
          else if (++blink_tmr[nr] > blink_rate)
          {
             std[nr]       = STD_LED_BLINK0;
             blink_tmr[nr] = 0;
          } // else if 
          break;
       case STD_LED_BLINK0:
          PD_ODR |= led; // LED off
          if (!(leds_out & blink_msk))
             std[nr] = STD_LED_OFF;
          else if (++blink_tmr[nr] > blink_rate)
          {
             std[nr]       = STD_LED_BLINK1;
             blink_tmr[nr] = 0;
          } // else if 
          break;  
   } // switch
} // set_one_led()

/*-----------------------------------------------------------------------------
  Purpose  : This routine multiplexes the 4 segments of the 7-segment displays.
             It runs at 1 kHz, so there's a full update after every 4 msec.
             The HC164 outputs are connected to the Command-Anodes of the 
             7-segment displays, so setting a 1 will enable that 7-segment.
  Variables: -
  Returns  : -
  ---------------------------------------------------------------------------*/
void multiplexer(void)
{
    LEDS_OFF;             // clear LEDs
    set_hc164(0x00);      // disable CA-lines of 7-segment displays
    PE_ODR |= SEG7_C;     // disable 7-segment display C
    PD_ODR |= PORTD_OUT;  // disable all other 7-segment displays
    
    switch (mpx_nr)
    {
        case 0: // output CA1 BOTTOM display (LSB)
            PE_ODR &= ~PE_LEDS(bot_01);   // Update PE0 (SEG7_C)
            PD_ODR &= ~PD_LEDS(bot_01);   // Update all other segments
            set_hc164(0x01);
            mpx_nr = 1;
            break;
        case 1: // output CA2 BOTTOM display
            PE_ODR &= ~PE_LEDS(bot_1);   // Update PE0 (SEG7_C)
            PD_ODR &= ~PD_LEDS(bot_1);   // Update all other segments
            set_hc164(0x02);
            mpx_nr = 2;
            break;
        case 2: // output CA3 BOTTOM display
            PE_ODR &= ~PE_LEDS(bot_10);   // Update PE0 (SEG7_C)
            PD_ODR &= ~PD_LEDS(bot_10);   // Update all other segments
            set_hc164(0x04);
            mpx_nr = 3;
            break;
        case 3: // outputs CA4 BOTTOM display (MSB)
            PE_ODR &= ~PE_LEDS(bot_100);  // Update PE0 (SEG7_C)
            PD_ODR &= ~PD_LEDS(bot_100);  // Update all other segments
            set_hc164(0x08);
            mpx_nr = 4;
            break;
        case 4: // set Frontpanel LEDs
            set_hc164(0x00);
            LEDS_ENABLE;
            set_one_led(0,LED_ALM1, LED_ALM1_BLINK, LED_ALM1_BLINK_FAST);
            set_one_led(1,LED_ALM2, LED_ALM2_BLINK, LED_ALM2_BLINK_FAST);
            set_one_led(2,LED_OUT1, LED_OUT1_BLINK, LED_OUT1_BLINK_FAST);
            set_one_led(3,LED_AT  , LED_AT_BLINK  , LED_AT_BLINK_FAST);
            mpx_nr = 5;
            break;
        case 5: // output CA1 TOP display (LSB)
            PE_ODR &= ~PE_LEDS(top_01);  // Update PE0 (SEG7_C)
            PD_ODR &= ~PD_LEDS(top_01);  // Update all other segments
            set_hc164(0x10);
            mpx_nr = 6;
            break;
        case 6: // output CA2 TOP display
            PE_ODR &= ~PE_LEDS(top_1);   // Update PE0 (SEG7_C)
            PD_ODR &= ~PD_LEDS(top_1);   // Update all other segments
            set_hc164(0x20);
            mpx_nr = 7;
            break;
        case 7: // output CA3 TOP display
            PE_ODR &= ~PE_LEDS(top_10);  // Update PE0 (SEG7_C)
            PD_ODR &= ~PD_LEDS(top_10);  // Update all other segments
            set_hc164(0x40);
            mpx_nr = 8;
            break;
        case 8: // outputs CA4 TOP display (MSB)
            PE_ODR &= ~PE_LEDS(top_100); // Update PE0 (SEG7_C)
            PD_ODR &= ~PD_LEDS(top_100); // Update all other segments
            set_hc164(0x80);
        default: // FALL-THROUGH (less code-size)
            mpx_nr = 0;
            break;
    } // switch            
} // multiplexer()

/*-----------------------------------------------------------------------------
  Purpose  : This is the interrupt routine for the Timer 2 Overflow handler.
             It runs at 1 kHz and drives the scheduler and the multiplexer.
  Variables: -
  Returns  : -
  ---------------------------------------------------------------------------*/
#pragma vector = TIM2_OVR_UIF_vector
@interrupt void TIM2_UPD_OVF_IRQHandler(void)
{
    scheduler_isr();  // Run scheduler interrupt function
    t2_millis++;      // update millisecond counter
    if (!pwr_on)
    {   // Display OFF on dispay
        top_100    = top_10 = top_1 = top_01 = bot_01 = LED_OFF;
        bot_100    = LED_O; 
        bot_10     = bot_1 = LED_F;
        pwr_on_tmr = 2000; // 2 seconds
    } // if
    else if (pwr_on_tmr > 0)
    {	// 7-segment display test for 2 seconds
        pwr_on_tmr--;
        top_100 = LED_C; top_10 = LED_1; top_1 = top_01 = LED_0;
        bot_100 = LED_P; bot_10 = LED_I; bot_1 = LED_d; bot_01 = LED_c;
    } // else if
    multiplexer();             // Run multiplexer for Display and Keys
    TIM2_SR1 &= ~TIM2_SR1_UIF; // Reset interrupt (UIF bit) so it will not fire again straight away.
} // TIM2_UPD_OVF_IRQHandler()

/*-----------------------------------------------------------------------------
  Purpose  : This routine initialises Timer 2 to generate a 1 kHz interrupt.
             16 MHz / (  16 *  1000) = 1000 Hz (1000 = 0x03E8)
  Variables: -
  Returns  : -
  ---------------------------------------------------------------------------*/
void setup_timer2(void)
{
    TIM2_PSCR = 0x04;         //  Prescaler = 16
    TIM2_ARRH = 0x03;         //  High byte of 1000
    TIM2_ARRL = 0xE8;         //  Low  byte of 1000
    TIM2_IER  = TIM2_IER_UIE; //  Enable the update interrupts, disable all others
    TIM2_CR1  = TIM2_CR1_CEN; //  Finally enable the timer
} // setup_timer2()

/*-----------------------------------------------------------------------------
  Purpose  : This routine initialises all the GPIO pins of the STM8 uC.
             See c100_pid_main.h for a detailed description of all pin-functions.
  Variables: -
  Returns  : -
  ---------------------------------------------------------------------------*/
void setup_gpio_ports(void)
{
    //-------------------------------------------------------------------
    // Initialise all PORTA IO: SSR and Alarm outputs
    //-------------------------------------------------------------------
    PA_DDR     |=   SSR | ALARM;         // Set PORTA pins as outputs
    PA_CR1     |=   SSR | ALARM;         // Set output pins to Push-Pull
    PA_ODR     &= ~(SSR | ALARM);        // Disable SSR and Alarm outputs
    
    //-------------------------------------------------------------------
    // Initialise all PORTB IO: SPI Chip-selects and Enable
    //-------------------------------------------------------------------
    PB_DDR     |=  PORTB_OUT;            // Set PORTB pins as outputs
    PB_CR1     |=  PORTB_OUT;            // Set output pins to Push-Pull
    PB_ODR     |= (CS_TC | CS_PT100 | CS_NRF24L01); // Disable SPI Chip-Selects
    PB_ODR     &= ~CE_NRF24L01;          // Set CE for NRF24L01 low
    
    //-------------------------------------------------------------------
    // Initialise all PORTC IO: SPI IO, HC164 controls, LEDS, KEYS
    //-------------------------------------------------------------------
    PC_ODR     &= ~PORTC_OUT;            // Turn off all pins from Port C
    PC_DDR     |= PORTC_OUT;             // Set PORTC pins as outputs
    PC_CR1     |= PORTC_OUT;             // Set output pins to Push-Pull
	PC_CR2     |=  (SPI_MOSI | SPI_SCK); // Set to 10 MHz
    PC_ODR     &= ~(SPI_MOSI | SPI_SCK); // MOSI = 0, SPI_CLK = 0
    PC_DDR     &= ~PORTC_IN;             // set PORTC pins as inputs
	PC_CR1     &= ~PORTC_IN;             // set input pins to Floating
    LEDS_OFF;                            // Disable frontpanel LEDs
    SET_SDIN_0;                          // Disable SDIN for HC164
    SET_CLK_0;                           // Disable CLK for HC164

    //-------------------------------------------------------------------
    // Initialise all PORTD IO: 7-segment display (and SWIM debug)
    //-------------------------------------------------------------------
    PD_DDR     |=  PORTD_OUT;            // Set PORTD pins as outputs
    PD_CR1     |=  PORTD_OUT;            // Set output pins to Push-Pull
    PD_ODR     &= ~PORTD_OUT;            // Disable 7-segment displays

    //-------------------------------------------------------------------
    // Initialise all PORTE IO: 1 7-segment display and I2C bus
    //-------------------------------------------------------------------
    PE_ODR     |=  (SPI_NSS | I2C_SCL | I2C_SDA);           // Must be set here, or I2C will not work
    PE_DDR     |=  (SPI_NSS | I2C_SCL | I2C_SDA | SEG7_C);  // Set as outputs
    PE_CR1     |=   SPI_NSS | SEG7_C;                       // Set output pin to Push-Pull
    PE_ODR     &=  ~SEG7_C;                                 // Disable 7-segment display
} // setup_gpio_ports()

/*-----------------------------------------------------------------------------
  Purpose  : This task is called every 100 msec. and creates a slow PWM signal
             from pid_output: T = 12.5 seconds. This signal can be used to
             drive a Solid-State Relay (SSR).
  Variables: pid_out (global) in E-1 %: 685 means 68.5 %
  Returns  : -
  ---------------------------------------------------------------------------*/
void pid_to_time(void)
{
    static uint8_t std_ptt = 1; // state [on, off]
    static uint8_t ltmr    = 0; // #times to set S3 to 0
    static uint8_t htmr    = 0; // #times to set S3 to 1
    int16_t pid = pid_out;      // copy of pid_out 
    uint8_t x;                  // temp. variable
     
    if (pid < 0) pid = -pid;
    x = (uint8_t)(pid >> 3); // divide by 8 to give 1.25 * pid_out
    
    switch (std_ptt)
    {
        case 0: // OFF
            if (!pwr_on) std_ptt = 2;
            else if (ltmr == 0)
            {   // End of low-time
                htmr = x; // htmr = 1.25 * pid_out
                if ((htmr > 0) && pwr_on) std_ptt = 1;
            } // if
            else ltmr--; // decrease timer
            SSR_OFF;     // SSR output = 0
            leds_out &= ~LED_OUT1; // disable OUT1 LED
            break;
        case 1: // ON
            if (!pwr_on) std_ptt = 2;
            else if (htmr == 0)
            {   // End of high-time
                ltmr = 125 - x; // ltmr = 1.25 * (100 - pid_out)
                if ((ltmr > 0) || !pwr_on) std_ptt = 0;
            } // if
            else htmr--; // decrease timer
            SSR_ON;      // SSR output = 1
            leds_out |= LED_OUT1; // enable OUT1 LED
            break;
        case 2: // DISABLED
            SSR_OFF; // SSR output = 0;
            leds_out &= ~LED_OUT1; // disable OUT1 LED
            if (pwr_on) std_ptt = 1;
            break;
    } // switch
} // pid_to_time()

/*-----------------------------------------------------------------------------
  Purpose  : This task is called every 500 msec. and reads the temperatures 
             from the thermocouple and from the PT100 sensor
  Variables: -
  Returns  : -
  ---------------------------------------------------------------------------*/
void adc_task(void)
{
    uint8_t err,err1;         // Error values
    int16_t temp_tc, temp_pt; // Values read from TC and PT100 sensors
    
    temp_err    = false;               // assume all is well
    temp_tc     = max31855_read(&err); // K-type thermocouple
    err1        = ((err & TC_ERR_OC) > 0);
    if (err1) 
    {   // No thermocouple sensor present, try PT100 sensor
        temp_tc_fil = TEMP_ROOM;           // reset TC-temperature to default
        temp_pt     = max31865_read(&err); // Read PT100 temperature
        if (err)
        {   // No sensors detected
            temp_pt_fil = TEMP_ROOM; // Reset PT100-temperature
            temp_tc_pt  = 0;         // Default temperature to 0.0 °C
            temp_err    = true;      // No sensors detected
        } // if
        else
        {   // PT100 sensor present and no TC sensor, so use PT100 temperature
            temp_pt_fil = ((temp_pt_fil - (temp_pt_fil >> FILTER_SHIFT)) + temp_pt);
            temp_tc_pt  = (int16_t)((temp_pt_fil + FILTER_ROUND) >> FILTER_SHIFT); 
            temp_tc_pt += eeprom_read_config(EEADR_MENU_ITEM(tc2));
        } // else
    } // if
    else
    {  // Thermocouple sensor present, so use that temperature
       temp_tc_fil = ((temp_tc_fil - (temp_tc_fil >> FILTER_SHIFT)) + temp_tc);
       temp_tc_pt  = (int16_t)((temp_tc_fil + FILTER_ROUND) >> FILTER_SHIFT); 
       temp_tc_pt += eeprom_read_config(EEADR_MENU_ITEM(tc));
    } // else
} // adc_task()

/*-----------------------------------------------------------------------------
  Purpose  : This task is called every 100 msec. and reads the buttons, runs
             the STD and updates the 7-segment display.
  Variables: -
  Returns  : -
  ---------------------------------------------------------------------------*/
void std_task(void)
{
    read_buttons(); // reads the buttons keys, result is stored in _buttons
    menu_fsm();     // Finite State Machine menu
    pid_to_time();  // Make Slow-PWM signal and send to Solid-State Relay (SSR)
} // std_task()
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
int main(void)
{
	long i;
	int ee = eedata[0]; // This is to prevent the linker from removing .eeprom section
	
	disable_interrupts();      // no interrupts yet
	initialise_system_clock(); // set main-clock to 16 MHz
	setup_gpio_ports();        // Initialise all GPIO ports
	setup_timer2();            // set TMR2 clock to 1 kHz for interrupt
    spi_init();                // Init. SPI interface
    max31865_init();           // Init. PT100 device
    
	// Initialise all tasks for the scheduler
    scheduler_init();                    // init. task scheduler
    add_task(adc_task ,"ADC",  0,  500); // every 500 msec.
    add_task(std_task ,"STD", 50,  100); // every 100 msec.
    add_task(ctrl_task,"CTL",200, 1000); // every second
    add_task(prfl_task,"PRF",300,60000); // every minute / hour
	enable_interrupts();                 // enable interrupts

	while (1)
	{ 	// background-processes
        dispatch_tasks();     // Run task-scheduler()
        wait_for_interrupt(); // do nothing
	} // while
} // main()

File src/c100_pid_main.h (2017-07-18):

#ifndef C100_PID_MAIN_H
#define C100_PID_MAIN_H
/*==================================================================
  File Name    : c100_pid_main.h
  Author       : Emile
  ------------------------------------------------------------------
  This is the main header file for the c100_pid project.
  ------------------------------------------------------------------
  c100_pid is free software: you can redistribute it and/or modify
  it under the terms of the GNU General Public License as published by
  the Free Software Foundation, either version 3 of the License, or
  (at your option) any later version.
 
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
  You should have received a copy of the GNU General Public License
  along with c100_pid.  If not, see <http://www.gnu.org/licenses/>.
  ------------------------------------------------------------------
  Schematic of the connections to the MCU.
  
                                 STM8S105C6T6
      MCU pin-name            Function |    MCU pin-name        Function
   ---------------------------------------|--------------------------------
   01 NRST                                | 13 VDDA
   02 PA1/OSC                 -           | 14 VSSA
   03 PA2/OSCOUT              ALARM       | 15 PB7/AIN7            CS_TC
   04 VSSIO_1                             | 16 PB6/AIN6            CS_PT100
   05 VSS                                 | 17 PB5/AIN5[I2C_SDA]   CS_NRF24L01
   06 VCAP                                | 18 PB4/AIN4[I2C_SCL]   CE_NRF24L01
   07 VDD                                 | 19 PB3/AIN3[TIM1_ETR]  -
   08 VDDIO_1                             | 20 PB2/AIN2[TIM1_CH3N] -
   09 PA3/TIM2_CH3[TIME3_CH1] SSR         | 21 PB1/AIN1[TIM1_CH2N] -
   10 PA4                     -           | 22 PB0/AIN0[TIM1_CH1N] -
   11 PA5                     -           | 23 PE7/AIN8            -
   12 PA6                     -           | 24 PE6/AIN9            -
   ---------------------------------------|--------------------------------
   25 PE5/SPI_NSS             -           | 37 PE3/TIM1_BKIN       -
   26 PC1/TIM1_CH1/UART2_CK   KEYS_COMMON | 38 PE2/I2C_SDA         I2C_SDA
   27 PC2/TIM1_CH2            LEDS_CTRL   | 39 PE1/I2C_SCL         I2C_SCL
   28 PC3/TIM1_CH3            SERIAL_IN   | 40 PE0/CLK_CC0         C
   29 PC4/TIM1_CH4            CLOCK       | 41 PD0/TIM3_CH2...     B
   30 PC5/SPI_SCK             SPI_SCK     | 42 PD1/SWIM            SWIM
   31 VSSIO_2                             | 43 PD2/TIM3_CH1...     A 
   32 VDDIO_2                             | 44 PD3/TIM2_CH2...     DP
   33 PC6/SPI_MOSI            SPI_MOSI    | 45 PD4/TIM2_CH1[BEEP]  G
   34 PC7/SPI_MISO            SPI_MISO    | 46 PD5/UART2_TX        F
   35 PG0                     -           | 47 PD6/UART2_RX        E
   36 PG1                     -           | 48 PD7/TLI[TIM1_CH4]   D
   ---------------------------------------------------------------------
*/
#include <iostm8s105.h>
#include "stdint.h"

/* Define STC-1000+ version number (XYY, X=major, YY=minor) */
/* Also, keep track of last version that has changes in EEPROM layout */
#define STC1000P_VERSION	    (300)
#define STC1000P_EEPROM_VERSION	 (20)

//-----------------------------------------------------------------------
// Hardware defines for register definitions
// These value were defined in IAR, but not in Cosmic STM8
//-----------------------------------------------------------------------
#define TIM2_SR1_UIF      (0x01)
#define CLK_ICKCR_HSIEN   (0x01)
#define CLK_ICKCR_HSIRDY  (0x02)
#define ADC_CR1_SPSEL_MSK (0x70)
#define CLK_SWCR_SWBSY    (0x01)
#define CLK_SWCR_SWEN     (0x02)
#define TIM2_IER_UIE      (0x01)
#define TIM2_CR1_CEN      (0x01)

#define enable_interrupts()  {_asm("rim\n");} /* enable interrupts */
#define disable_interrupts() {_asm("sim\n");} /* disable interrupts */
#define wait_for_interrupt() {_asm("wfi\n");} /* Wait For Interrupt */

//-----------------------------------------------------------------------
// PORTA Inputs and Outputs
//-----------------------------------------------------------------------
#define SSR         (0x08)
#define ALARM       (0x04)

#define SSR_ON        (PA_ODR |=  SSR)
#define SSR_OFF       (PA_ODR &= ~SSR)
#define SSR_STATUS   ((PA_IDR & SSR) == SSR)
#define ALARM_ON      (PA_ODR |=  ALARM)
#define ALARM_OFF     (PA_ODR &= ~ALARM)
#define ALARM_STATUS ((PA_IDR & ALARM) == ALARM)

//-----------------------------------------------------------------------
// PORTB Inputs and Outputs
//-----------------------------------------------------------------------
#define CS_TC       (0x80)
#define CS_PT100    (0x40)
#define CS_NRF24L01 (0x20)
#define CE_NRF24L01 (0x10)
#define PORTB_OUT   (CS_TC | CS_PT100 | CS_NRF24L01 | CE_NRF24L01)

#define CS_TC_0     (PB_ODR &= ~CS_TC)
#define CS_TC_1     (PB_ODR |=  CS_TC)
#define CS_PT100_0  (PB_ODR &= ~CS_PT100)
#define CS_PT100_1  (PB_ODR |=  CS_PT100)
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

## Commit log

2017-06-30 Readme updated with pictures from populated PCB
2017-06-30 Source files copied from existing project
    These sources do compile, but functionality is not tested yet. This is
    purely a preliminary set-up for the software environment.
    [c100_pid_stm8s105.stp]
2017-07-02 First working version on new hardware
    7-segment display now works + control of 4 frontpanel LEDs. The
    frontpanel LEDs can also be set to blinking (slow and fast). Buttons are
    also read in properly.
2017-07-04 Routines for MAX31855 (thermocouple) and MAX31865 (PT100) added.
    This is not tested yet, but sources do compile.
    [c100_pid_stm8s105.stp]
2017-07-17 Both sensors (TC and PT100) are working now!
    SPI interface fully debugged.
2017-07-18 Thermostat and PID now work and menu update. First fully functional version
    First fully working version, User_Manual added, README update.
